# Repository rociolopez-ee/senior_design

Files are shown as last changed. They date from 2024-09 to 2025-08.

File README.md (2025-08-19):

# 🎧 MultiLink Portable Bluetooth Speaker - KiCad Design Files

This repository contains the full **KiCad project files** for the Multilink Portable Bluetooth Speaker designed by **Team 5 – Synergy Electronics** as part of the **Senior Design Capstone at San Diego State University (EE/COMPE 492)**.

## 📦 What’s Inside

This repository includes:
- **Schematic files** for the main and secondary speaker PCBs
- **PCB layout** for a custom 4-layer board
- **Bill of Materials (BOM)**
- **Gerber files** for fabrication
- **Custom footprints and symbols**

> 🎯 These designs were used to build and test a working multilink Bluetooth audio system using STM32/ATmega microcontrollers, BM83 Bluetooth modules, and a custom audio amplification chain.

---

## 🔧 Project Overview

The MultiLink Portable Bluetooth Speaker was designed to:
- Support **multi-speaker synchronized audio** via BM83 Bluetooth modules (host/embedded mode)
- Include **custom power amplifier** and **op-amp gain stages** (LF353 + discrete PA)
- Be powered by **20V DeWalt tool batteries**
- Use **custom enclosures** built from birch wood and plexiglass

🧠 PCB design and layout were done using KiCad 7 and included thermal planning, decoupling, and signal integrity improvements based on EMI/grounding test results.

---

## 🧪 PCB Design Highlights

- ✍️ **4-layer PCB**, designed for both signal integrity and ease of debugging
- 🔁 **Op-amp gain stage** (V=4.3) before power amplifier (V=2.2) for total gain ≈ 9.4 V/V
- 💡 **BM83 Bluetooth module** with UART interface to microcontroller
- 🔌 **Volume, pairing, and power buttons** routed via microcontroller
- 🌡️ **Thermal design** included heatsinks for voltage regulator and amplifier transistors
- 🛠️ Manual fixes applied to final board: jumper wires and capacitor routing corrections

---
🎥 Project Demo: [YouTube Video](https://youtube.com/shorts/QWg84WqX6ao?feature=share)
---

## 👥 Team Members

- **Rocio Lopez** – Project Manager, Lead PCB Designer  
- **Po-Jui Su** – Power Systems Engineer  
- **Ryan Minsky** – Firmware Engineer ([@rminsky42](https://github.com/rminsky42))
- **Giuseppe Aiello** – Enclosure Designer, Secondary PCB Assembler  
- **Jeffrey Chin** – Project Coordinator  

---

## ⚠️ Disclaimer

This repository contains files for educational and demonstration purposes. No commercial use is authorized.

---

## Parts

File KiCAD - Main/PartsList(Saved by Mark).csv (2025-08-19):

Reference | Value | Datasheet | Footprint | Qty | DNP
20v1,Analog1,Audio1,Audio2,PAOut1,RX1,TP1,TP2,TP3,TP4,TPQ1,TPQ2,TX1 | TestPoint | ~ | -- mixed values -- | 13
C1 | 0.33uF | ~ | Capacitor_THT:C_Disc_D4.7mm_W2.5mm_P5.00mm | 1
C2 | 0.1uF | ~ | Capacitor_THT:C_Disc_D4.7mm_W2.5mm_P5.00mm | 1
C3,C7,C8 | 1uF | ~ | Capacitor_THT:C_Disc_D4.7mm_W2.5mm_P5.00mm | 3
C4 | 1nF | ~ | Capacitor_THT:C_Disc_D4.7mm_W2.5mm_P5.00mm | 1
C5 | 0.22uF | ~ | Capacitor_THT:C_Disc_D4.7mm_W2.5mm_P5.00mm | 1
C6 | 1000uF | ~ | Capacitor_THT:C_Disc_D4.7mm_W2.5mm_P5.00mm | 1
C9 | .1uF | ~ | Capacitor_THT:C_Disc_D4.7mm_W2.5mm_P5.00mm | 1
D1,D2 | 1N4148 | https://assets.nexperia.com/documents/data-sheet/1N4148_1N4448.pdf | Diode_THT:D_DO-15_P12.70mm_Horizontal | 2
D3,D4 | LED | ~ | LED_THT:LED_D3.0mm | 2
J1,J2 | Conn_01x01 | ~ | TestPoint:TestPoint_Keystone_5010-5014_Multipurpose | 2
J3,J7 | Conn_01x02 | ~ | Connector_PinHeader_2.54mm:PinHeader_1x02_P2.54mm_Vertical | 2
J4 | 6120XX21621_61200621621 |  | 61200621621:61200621621 | 1
J5,J6 | Conn_01x04 | ~ | Connector_PinHeader_2.00mm:PinHeader_1x04_P2.00mm_Vertical | 2
J8,J9,J11,J12 | Conn_01x12 | ~ | Connector_PinHeader_2.54mm:PinHeader_1x12_P2.54mm_Vertical | 4
J10 | Screw_Terminal_01x02 | ~ | TerminalBlock_Phoenix:TerminalBlock_Phoenix_MKDS-1,5-2-5.08_1x02_P5.08mm_Horizontal | 1
Q1,Q2 | BSS138 | https://www.onsemi.com/pub/Collateral/BSS138-D.PDF | Package_TO_SOT_SMD:SOT-23-3 | 2
Q3,Q5 | 2N3904 | https://www.onsemi.com/pub/Collateral/2N3903-D.PDF | Package_TO_SOT_THT:TO-92_Wide | 2
Q4 | 2N3906 | https://www.onsemi.com/pub/Collateral/2N3906-D.PDF | Package_TO_SOT_THT:TO-92_Wide | 1
Q6 | 2SB817 | http://skory.gylcomp.hu/alkatresz/2SB817.pdf | Package_TO_SOT_THT:TO-220-3_Vertical | 1
Q7 | 2SD1047 | http://www.st.com/resource/en/datasheet/2sd1047.pdf | Package_TO_SOT_THT:TO-220-3_Vertical | 1
R1,R2,R4,R5,R6,R7,R8,R16,R17 | 10k | ~ | Resistor_THT:R_Axial_DIN0309_L9.0mm_D3.2mm_P12.70mm_Horizontal | 9
R3 | 5k | ~ | Resistor_THT:R_Axial_DIN0309_L9.0mm_D3.2mm_P12.70mm_Horizontal | 1
R9,R10 | 2k | ~ | Resistor_THT:R_Axial_DIN0309_L9.0mm_D3.2mm_P12.70mm_Horizontal | 2
R11 | 3.3k | ~ | Resistor_THT:R_Axial_DIN0309_L9.0mm_D3.2mm_P12.70mm_Horizontal | 1
R12,R14 | 4.7k | ~ | Resistor_THT:R_Axial_DIN0309_L9.0mm_D3.2mm_P12.70mm_Horizontal | 2
R13 | 1000 | ~ | Resistor_THT:R_Axial_DIN0309_L9.0mm_D3.2mm_P12.70mm_Horizontal | 1
R15 | 12k | ~ | Resistor_THT:R_Axial_DIN0309_L9.0mm_D3.2mm_P12.70mm_Horizontal | 1
R18,R19 | 0.22 | ~ | Resistor_THT:R_Axial_DIN0309_L9.0mm_D3.2mm_P12.70mm_Horizontal | 2
RV1 | R_Potentiometer_US | ~ | Potentiometer_THT:Potentiometer_Bourns_3386P_Vertical | 1
U1 | L78L05_TO220 | http://www.st.com/content/ccc/resource/technical/document/datasheet/15/55/e5/aa/23/5b/43/fd/CD00000446.pdf/files/CD00000446.pdf/jcr:content/translations/en.CD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 | Package_TO_SOT_THT:TO-220-3_Vertical | 1
U2 | ATmega328PB-A | http://ww1.microchip.com/downloads/en/DeviceDoc/40001906C.pdf | Package_QFP:TQFP-32_7x7mm_P0.8mm | 1
U3 | LF353N | https://www.ti.com/lit/ds/symlink/lf353-n.pdf | Package_DIP:DIP-8_W7.62mm_Socket | 1
U4 | Microchip_BM83 | https://ww1.microchip.com/downloads/aemDocuments/documents/WSG/ProductDocuments/DataSheets/70005402E.pdf | RF_Module:Microchip_BM83 | 1

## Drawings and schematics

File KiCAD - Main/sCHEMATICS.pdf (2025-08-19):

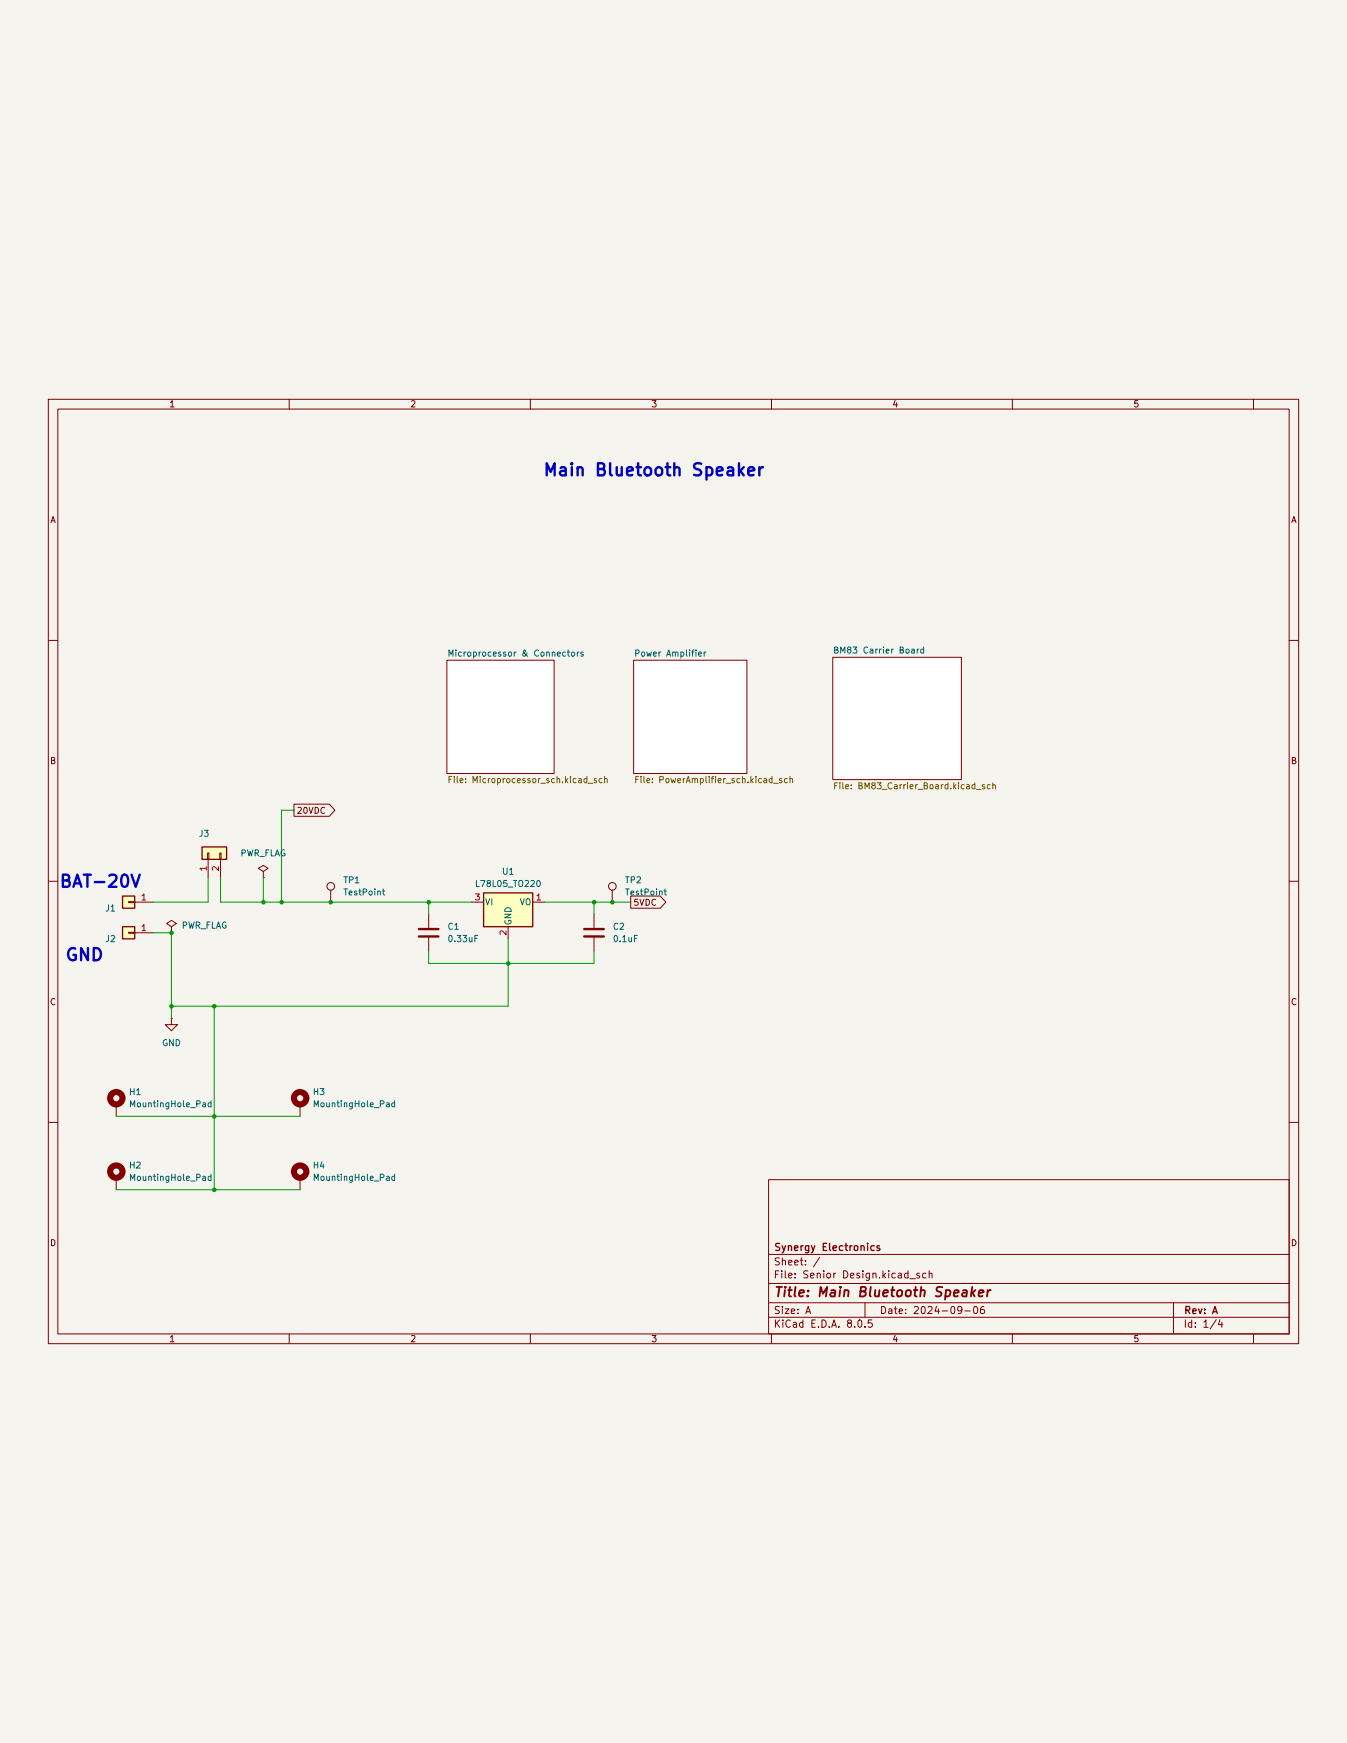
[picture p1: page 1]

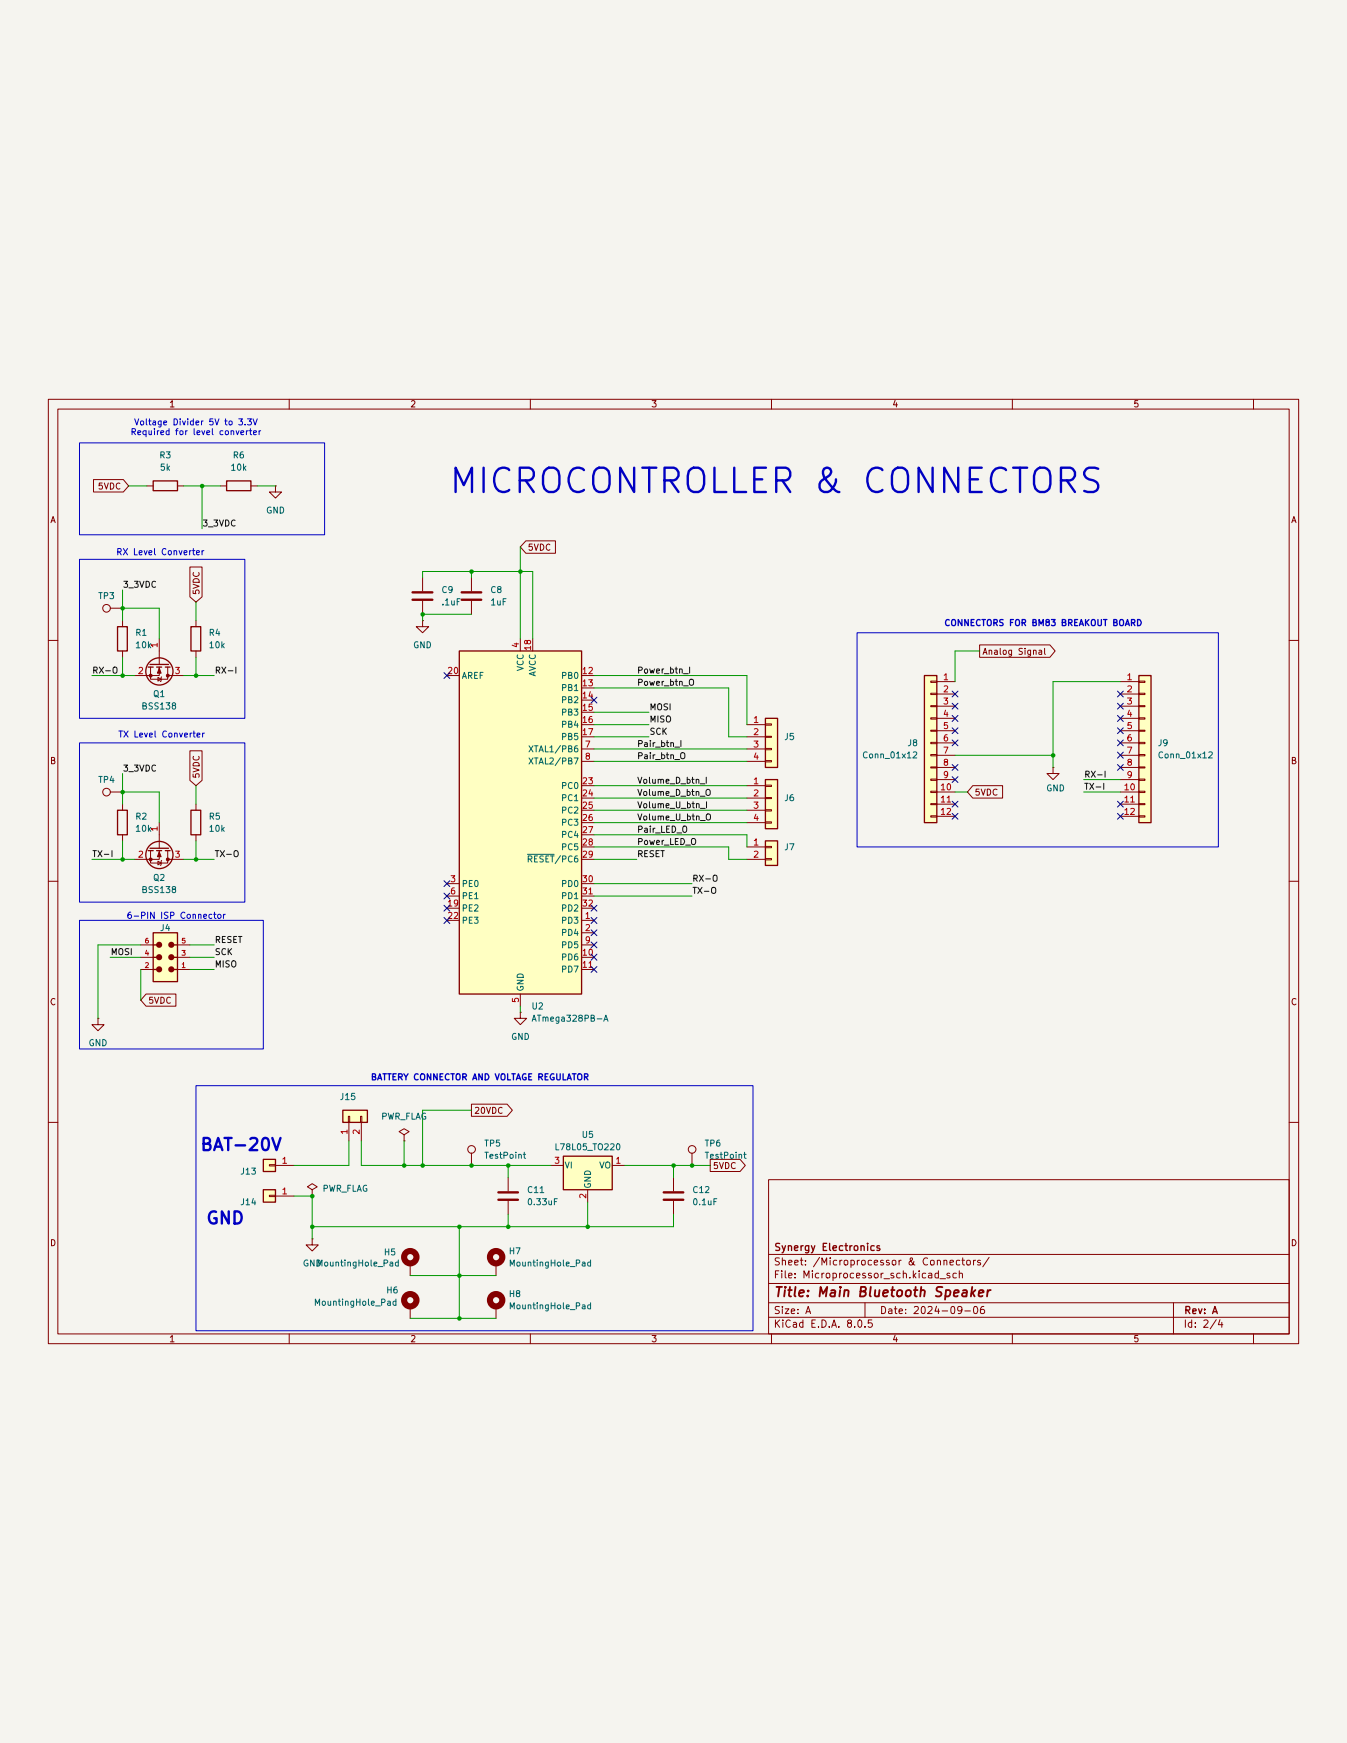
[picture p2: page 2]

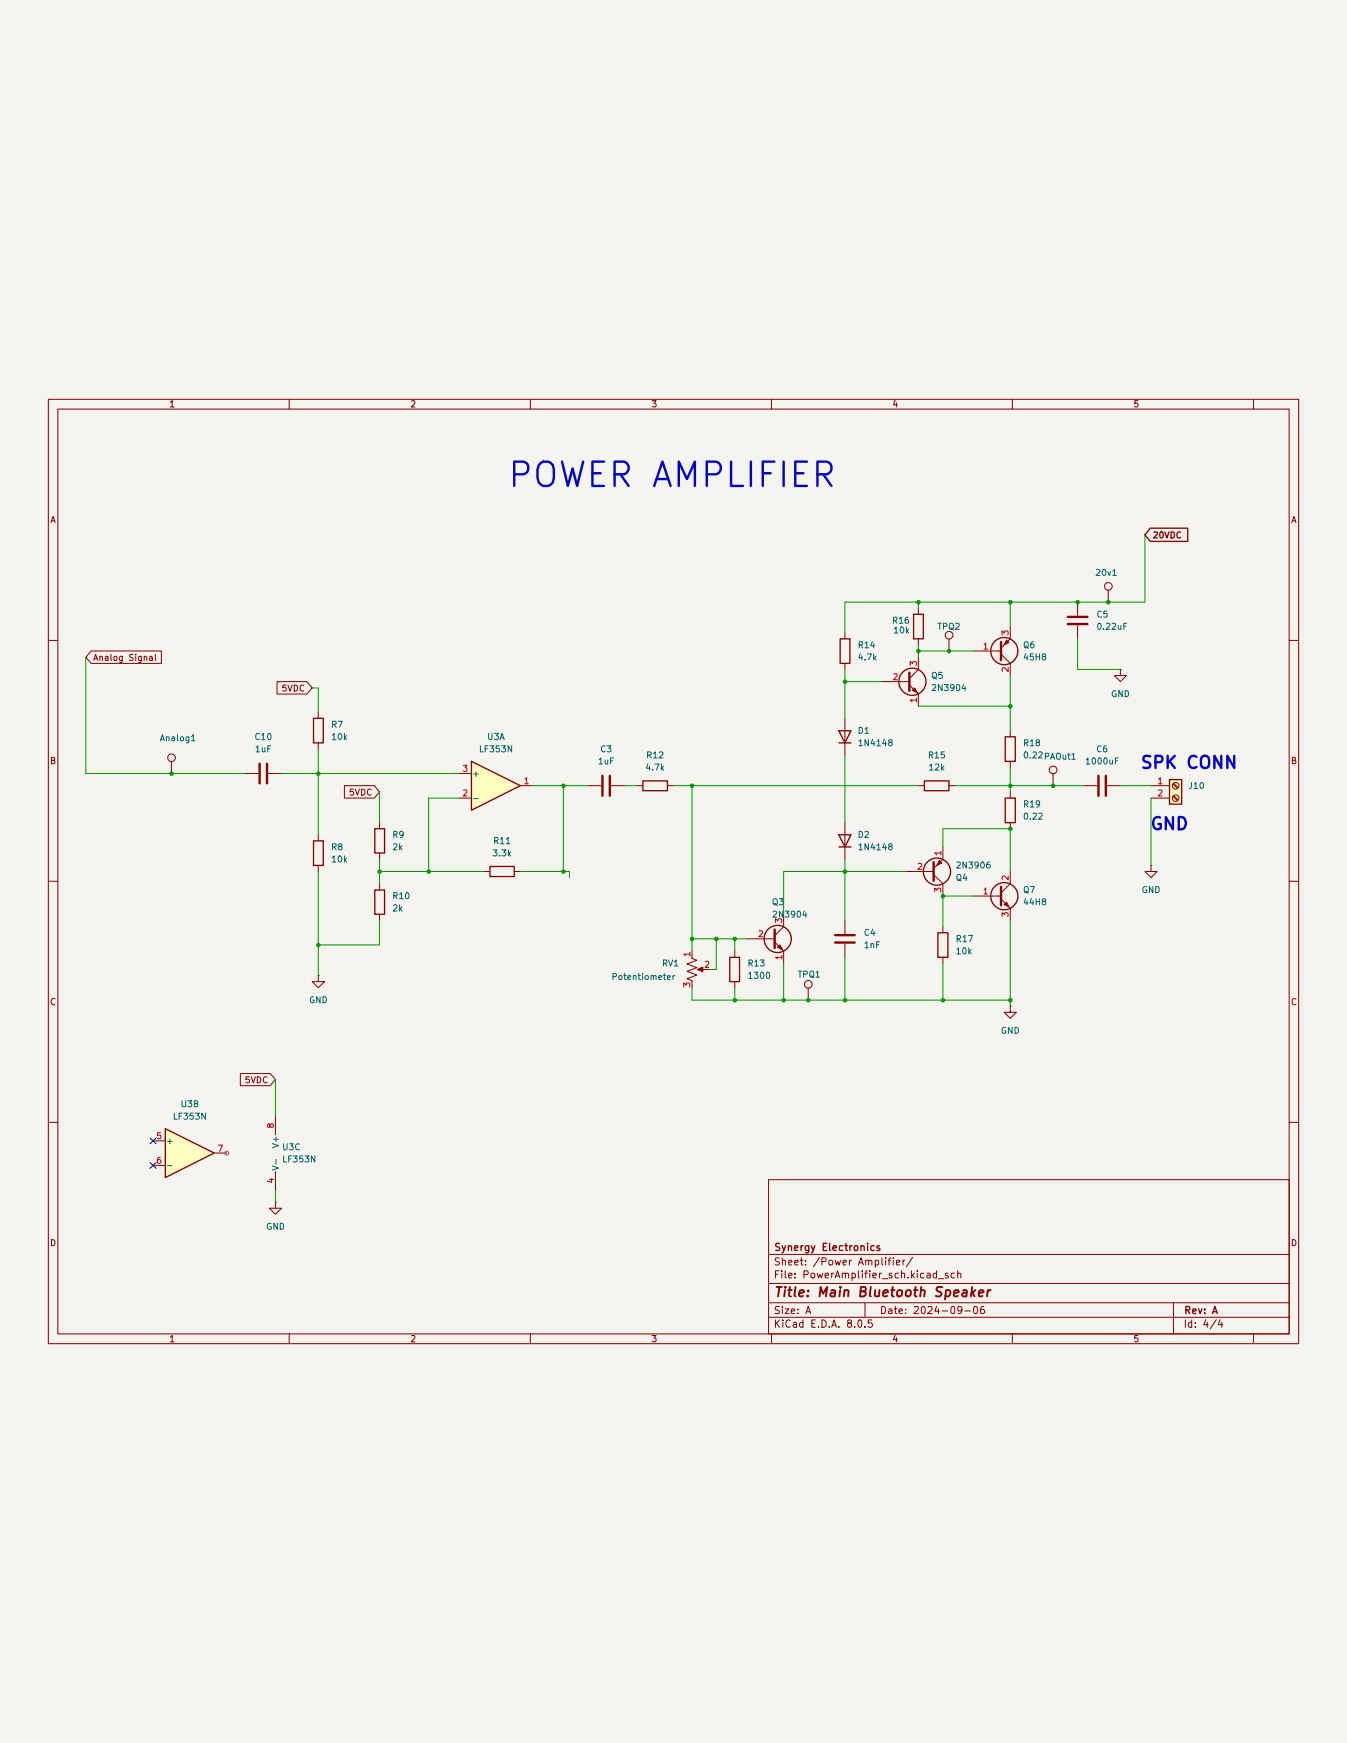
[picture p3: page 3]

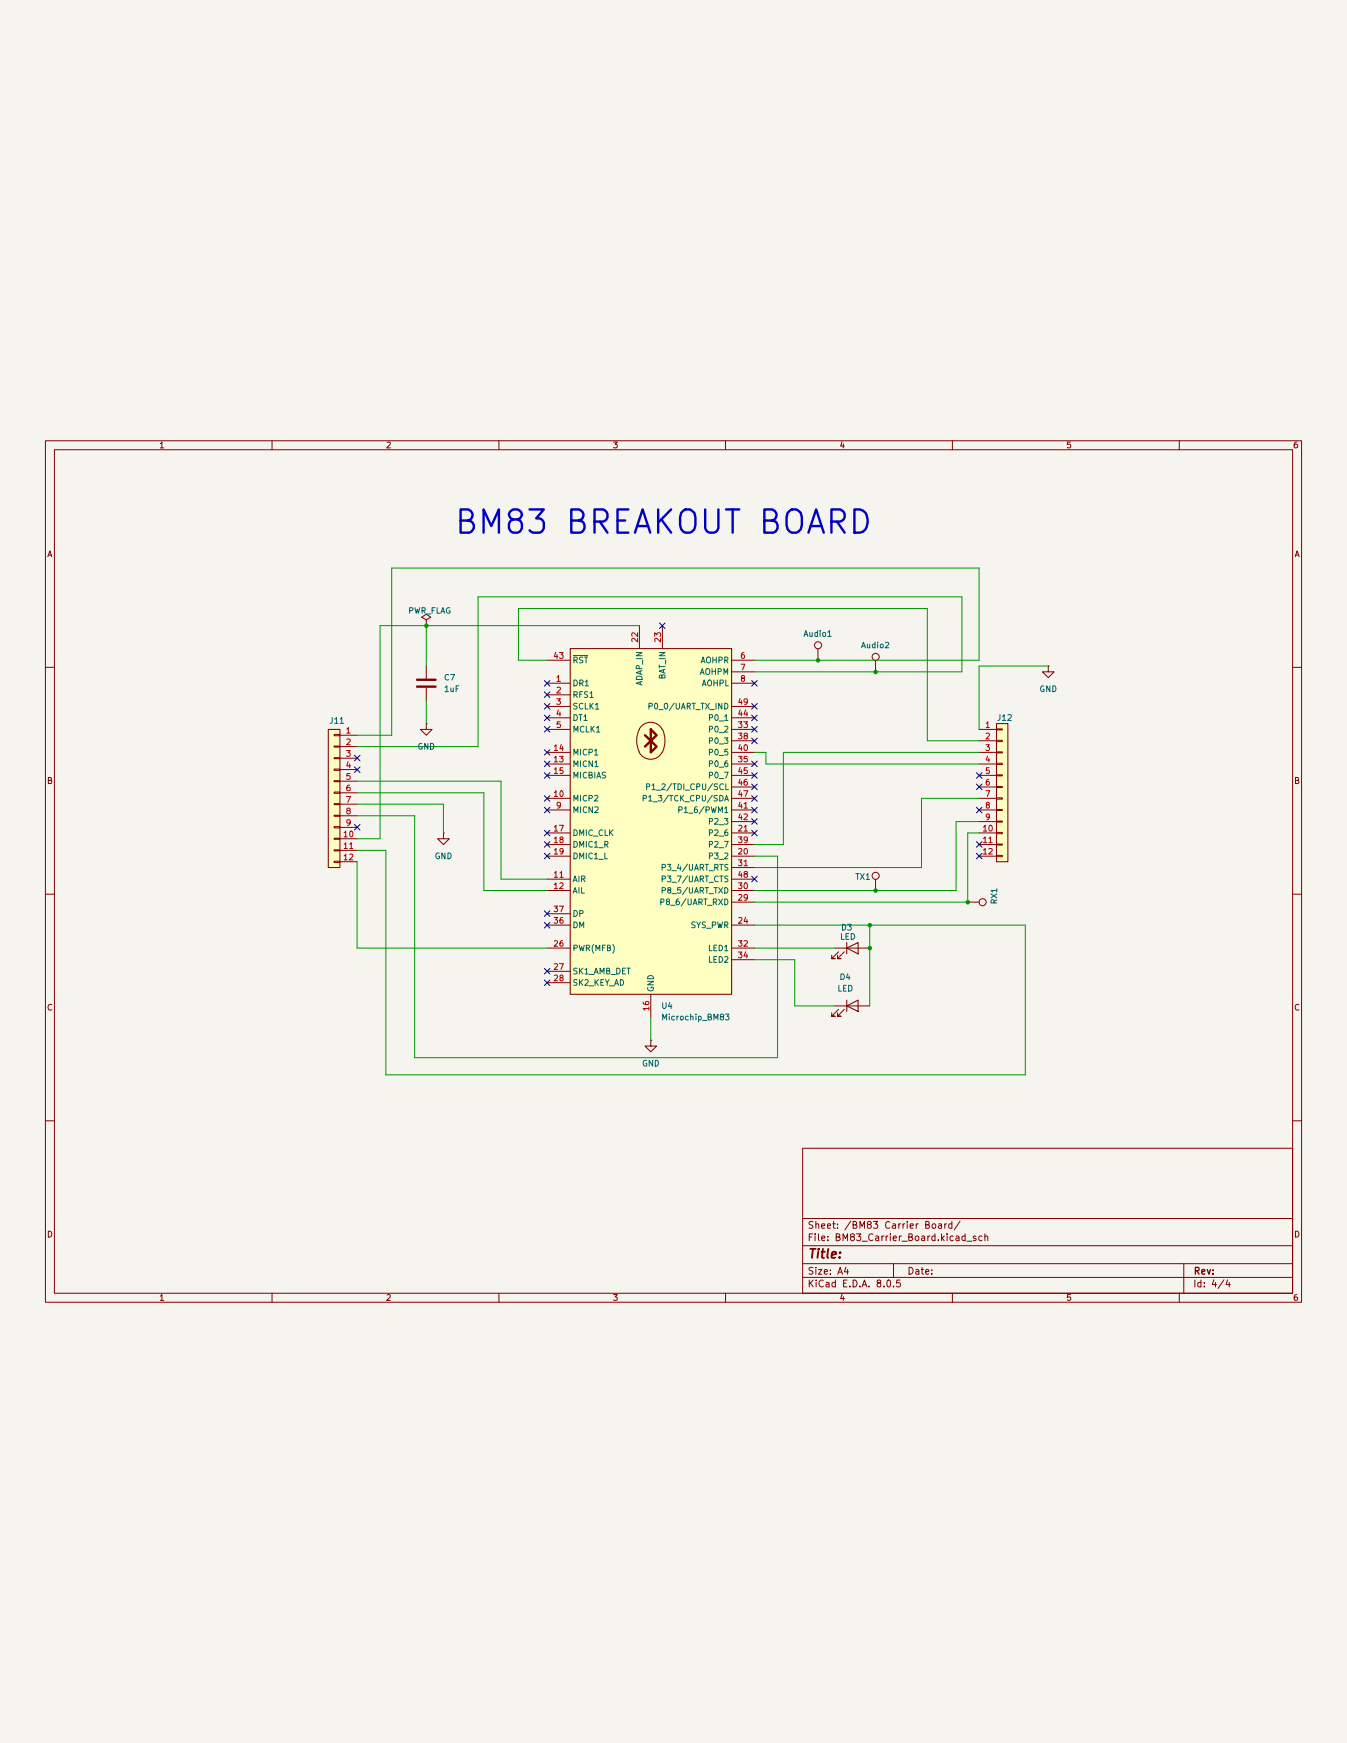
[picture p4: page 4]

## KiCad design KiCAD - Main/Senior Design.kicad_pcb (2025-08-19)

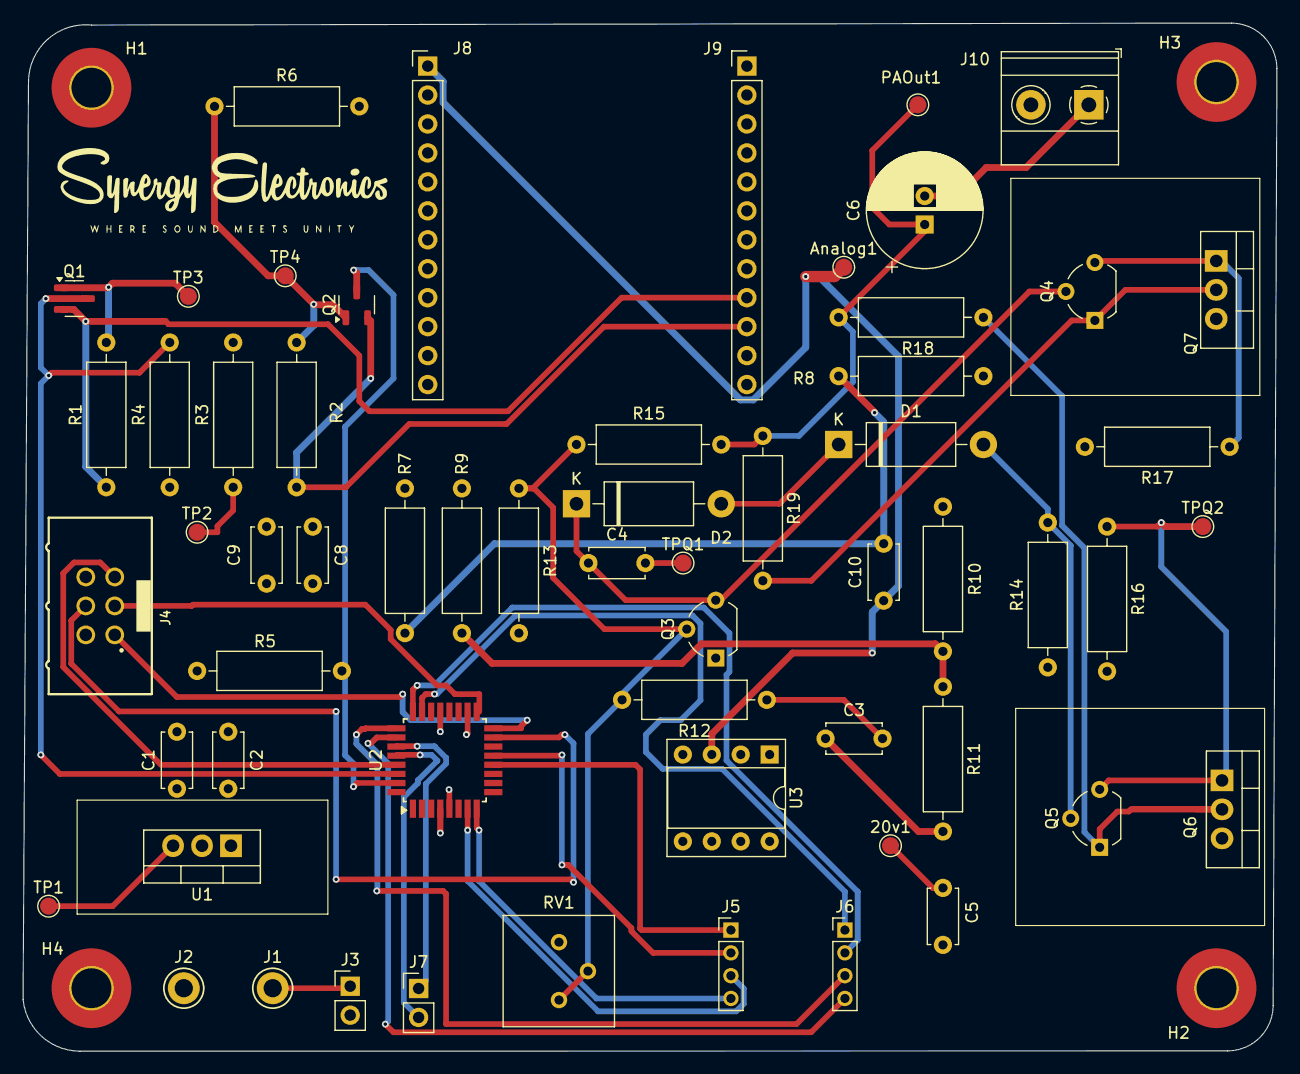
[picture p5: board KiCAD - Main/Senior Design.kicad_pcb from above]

Board: 4 copper layers, 110.0 x 90.2 mm, 64 parts (0 on the bottom side), 38 nets.

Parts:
20v1: TestPoint; TestPoint_Pad_D1.5mm
Analog1: TestPoint; TestPoint_Pad_D1.5mm
C1: 0.33uF; C_Disc_D4.7mm_W2.5mm_P5.00mm
C2: 0.1uF; C_Disc_D4.7mm_W2.5mm_P5.00mm
C3, C8, C10: 1uF; C_Disc_D4.7mm_W2.5mm_P5.00mm
C4: 1nF; C_Disc_D4.7mm_W2.5mm_P5.00mm
C5: 0.22uF; C_Disc_D4.7mm_W2.5mm_P5.00mm
C6: 1000uF; CP_Radial_D10.0mm_P2.50mm
C9: .1uF; C_Disc_D4.7mm_W2.5mm_P5.00mm
D1, D2: 1N4148; D_DO-15_P12.70mm_Horizontal
H1, H2, H3, H4: MountingHole_Pad; MountingHole_3.5mm_Pad_TopBottom
J1, J2: Conn_01x01; TestPoint_Keystone_5010-5014_Multipurpose
J3, J7: Conn_01x02; PinHeader_1x02_P2.54mm_Vertical
J4: 6120XX21621_61200621621; 61200621621
J5, J6: Conn_01x04; PinHeader_1x04_P2.00mm_Vertical
J8, J9: Conn_01x12; PinHeader_1x12_P2.54mm_Vertical
J10: Screw_Terminal_01x02; TerminalBlock_Phoenix_MKDS-1,5-2-5.08_1x02_P5.08mm_Horizont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
PAOut1: TestPoint; TestPoint_Pad_D1.5mm
Q1, Q2: BSS138; SOT-23-3
Q3, Q5: 2N3904; TO-92_Wide
Q4: 2N3906; TO-92_Wide
Q6: D45H8; TO-220-3_Vertical
Q7: D44H8; TO-220-3_Vertical
R1, R2, R4, R5, R6, R7, R8, R16, R17: 10k; R_Axial_DIN0309_L9.0mm_D3.2mm_P12.70mm_Horizontal
R3: 5k; R_Axial_DIN0309_L9.0mm_D3.2mm_P12.70mm_Horizontal
R9, R10: 2k; R_Axial_DIN0309_L9.0mm_D3.2mm_P12.70mm_Horizontal
R11: 3.3k; R_Axial_DIN0309_L9.0mm_D3.2mm_P12.70mm_Horizontal
R12, R14: 4.7k; R_Axial_DIN0309_L9.0mm_D3.2mm_P12.70mm_Horizontal
R13: 1000; R_Axial_DIN0309_L9.0mm_D3.2mm_P12.70mm_Horizontal
R15: 12k; R_Axial_DIN0309_L9.0mm_D3.2mm_P12.70mm_Horizontal
R18, R19: 0.22; R_Axial_DIN0309_L9.0mm_D3.2mm_P12.70mm_Horizontal
RV1: R_Potentiometer_US; Potentiometer_Bourns_3386P_Vertical
TP1, TP2, TP3, TP4: TestPoint; TestPoint_Pad_D1.5mm
TPQ1, TPQ2: TestPoint; TestPoint_Pad_D1.5mm
U1: L78L05_TO220; TO-220-3_Vertical
U2: ATmega328PB-A; TQFP-32_7x7mm_P0.8mm
U3: LF353N; DIP-8_W7.62mm_Socket

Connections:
5VDC: C2.1, C8.1, C9.1, J4.2, J8.10, R3.1, R4.1, R5.1, R7.1, R9.1, TP2.1, U1.1 (VO), U2.4 (VCC), U2.18 (AVCC), U3.8 (V+)
20VDC: 20v1.1, C1.1, C5.1, J3.2, Q6.3 (E), R14.1, R16.2, TP1.1, U1.3 (VI)
/Microprocessor & Connectors/3_3VDC: Q1.1 (G), Q2.1 (G), R1.1, R2.1, R3.2, R6.1, TP3.1, TP4.1
/Microprocessor & Connectors/MISO: J4.1, U2.16 (PB4)
/Microprocessor & Connectors/MOSI: J4.4, U2.15 (PB3)
/Microprocessor & Connectors/Pair_LED_O: J7.1, U2.27 (PC4)
/Microprocessor & Connectors/Pair_btn_I: J5.3, U2.7 (XTAL1/PB6)
/Microprocessor & Connectors/Pair_btn_O: J5.4, U2.8 (XTAL2/PB7)
/Microprocessor & Connectors/Power_LED_O: J7.2, U2.28 (PC5)
/Microprocessor & Connectors/Power_btn_I: J5.1, U2.12 (PB0)
/Microprocessor & Connectors/Power_btn_O: J5.2, U2.13 (PB1)
/Microprocessor & Connectors/RESET: J4.5, U2.29 (~RESET/PC6)
/Microprocessor & Connectors/RX-I: J9.9, Q1.2 (S), R1.2
/Microprocessor & Connectors/RX-O: Q1.3 (D), R4.2, U2.30 (PD0)
/Microprocessor & Connectors/SCK: J4.3, U2.17 (PB5)
/Microprocessor & Connectors/TX-I: J9.10, Q2.2 (S), R2.2
/Microprocessor & Connectors/TX-O: Q2.3 (D), R5.2, U2.31 (PD1)
/Microprocessor & Connectors/Volume_D_btn_I: J6.1, U2.23 (PC0)
/Microprocessor & Connectors/Volume_D_btn_O: J6.2, U2.24 (PC1)
/Microprocessor & Connectors/Volume_U_btn_I: J6.3, U2.25 (PC2)
/Microprocessor & Connectors/Volume_U_btn_O: J6.4, U2.26 (PC3)
Analog Signal: Analog1.1, C10.1, J8.1, U3.3 (POSA)
GND: C1.2, C2.2, C4.2, C5.2, C8.2, C9.2, H1.1, H2.1, H3.1, H4.1, J2.1, J4.6, J8.7, J9.1, J10.2, Q3.1 (E), Q7.3 (E), R6.2, R8.2, R10.2, R13.2, R17.2, RV1.3, TPQ1.1, U1.2 (GND), U2.5 (GND), U2.21 (GND), U3.4 (V-)
unnamed: C3.1, R11.2
unnamed: C3.2, R12.1
unnamed: C6.1, PAOut1.1, R15.2, R18.2, R19.1
unnamed: D1.2 (A), Q5.2 (B), R14.2
unnamed: D1.1 (K), D2.2 (A)
unnamed: C4.1, D2.1 (K), Q3.3 (C), Q4.2 (B)
unnamed: J1.1, J3.1
unnamed: C6.2, J10.1
unnamed: Q3.2 (B), R12.2, R13.1, R15.1, RV1.1, RV1.2
unnamed: Q4.3 (C), Q7.1 (B), R17.1
unnamed: Q4.1 (E), Q7.2 (C), R19.2
unnamed: Q5.3 (C), Q6.1 (B), R16.1, TPQ2.1
unnamed: Q5.1 (E), Q6.2 (C), R18.1
unnamed: C10.2, R7.2, R8.1
unnamed: R9.2, R10.1, R11.1

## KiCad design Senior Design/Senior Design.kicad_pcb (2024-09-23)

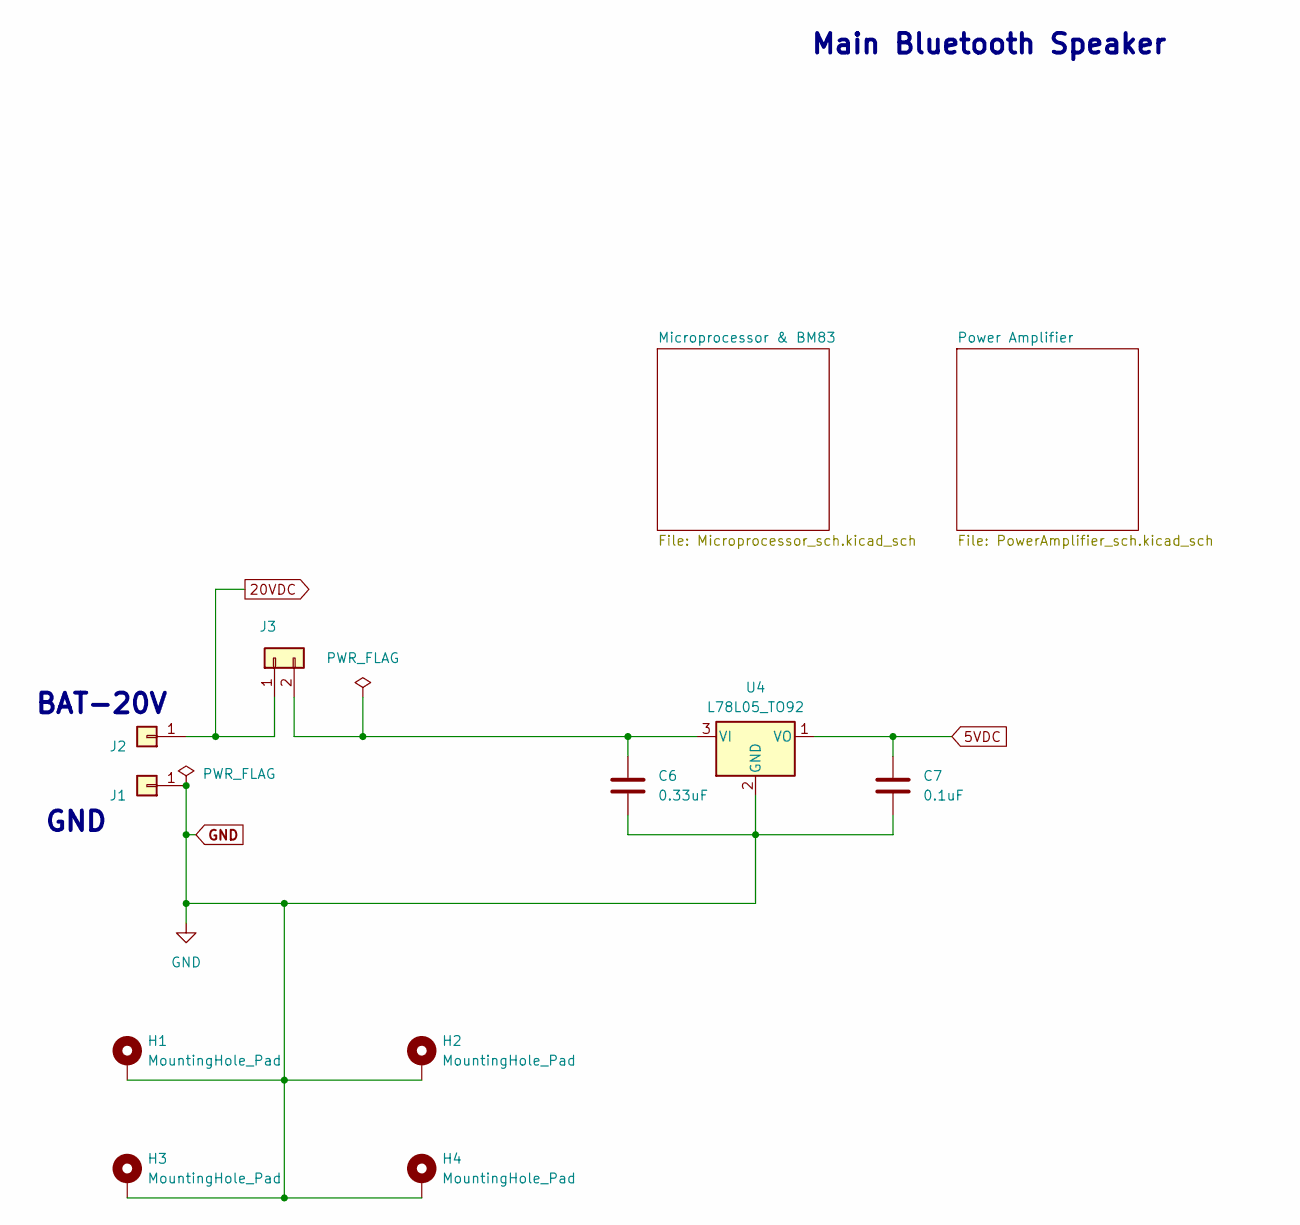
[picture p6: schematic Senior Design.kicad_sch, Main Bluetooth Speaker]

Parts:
C6: 0.33uF; C_Disc_D4.7mm_W2.5mm_P5.00mm
C7: 0.1uF; C_Disc_D4.7mm_W2.5mm_P5.00mm
H1, H2, H3, H4: MountingHole_Pad; MountingHole_3.5mm_Pad_TopBottom
J1, J2: Conn_01x01; TestPoint_Keystone_5010-5014_Multipurpose
J3: Conn_01x02; PinHeader_1x02_P2.54mm_Vertical
U4: L78L05_TO92; TO-92_Wide

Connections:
5VDC: C7.1, U4.1 (VO); also elsewhere on the board
20VDC: J2.1, J3.1; also elsewhere on the board
GND: C6.2, C7.2, H1.1, H2.1, H3.1, H4.1, J1.1, U4.2 (GND); also elsewhere on the board
unnamed: C6.1, J3.2, U4.3 (VI)

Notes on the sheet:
BAT-20V
GND
Main Bluetooth Speaker

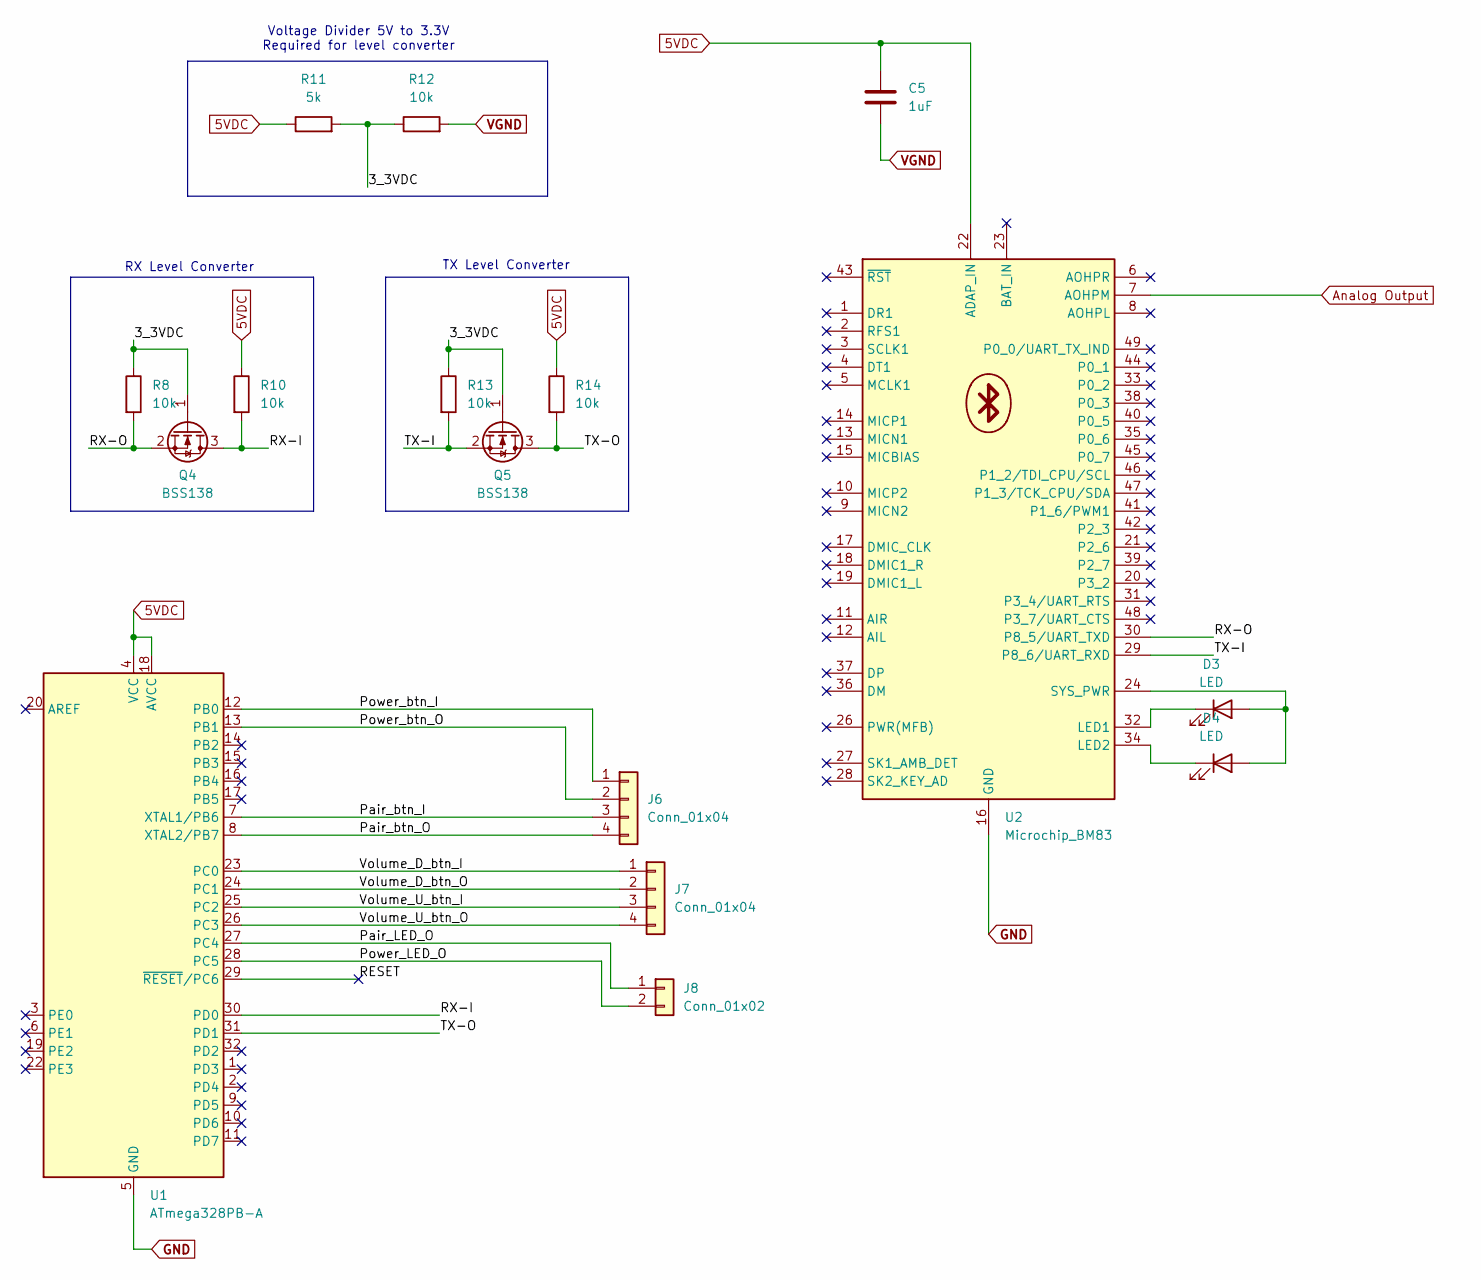
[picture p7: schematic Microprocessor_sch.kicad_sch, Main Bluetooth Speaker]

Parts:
C5: 1uF; C_Disc_D4.7mm_W2.5mm_P5.00mm
D3, D4: LED; LED_D5.0mm
J6, J7: Conn_01x04; PinHeader_1x04_P2.54mm_Vertical
J8: Conn_01x02; PinHeader_1x02_P2.54mm_Vertical
Q4, Q5: BSS138; SOT-23-3
R8, R10, R12, R13, R14: 10k; R_Axial_DIN0309_L9.0mm_D3.2mm_P12.70mm_Horizontal
R11: 5k; R_Axial_DIN0309_L9.0mm_D3.2mm_P12.70mm_Horizontal
U1: ATmega328PB-A; TQFP-32_7x7mm_P0.8mm
U2: Microchip_BM83

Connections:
5VDC: C5.1, R10.1, R11.1, R14.1, U1.4 (VCC), U1.18 (AVCC), U2.22 (ADAP_IN); also elsewhere on the board
/Microprocessor & BM83/3_3VDC: Q4.1 (G), Q5.1 (G), R8.1, R11.2, R12.1, R13.1
/Microprocessor & BM83/Pair_LED_O: J8.1, U1.27 (PC4)
/Microprocessor & BM83/Pair_btn_I: J6.3, U1.7 (XTAL1/PB6)
/Microprocessor & BM83/Pair_btn_O: J6.4, U1.8 (XTAL2/PB7)
/Microprocessor & BM83/Power_LED_O: J8.2, U1.28 (PC5)
/Microprocessor & BM83/Power_btn_I: J6.1, U1.12 (PB0)
/Microprocessor & BM83/Power_btn_O: J6.2, U1.13 (PB1)
/Microprocessor & BM83/RESET: U1.29 (~RESET/PC6)
/Microprocessor & BM83/RX-I: Q4.3 (D), R10.2, U1.30 (PD0)
/Microprocessor & BM83/RX-O: Q4.2 (S), R8.2, U2.30 (P8_5/UART_TXD)
/Microprocessor & BM83/TX-I: Q5.2 (S), R13.2, U2.29 (P8_6/UART_RXD)
/Microprocessor & BM83/TX-O: Q5.3 (D), R14.2, U1.31 (PD1)
/Microprocessor & BM83/Volume_D_btn_I: J7.1, U1.23 (PC0)
/Microprocessor & BM83/Volume_D_btn_O: J7.2, U1.24 (PC1)
/Microprocessor & BM83/Volume_U_btn_I: J7.3, U1.25 (PC2)
/Microprocessor & BM83/Volume_U_btn_O: J7.4, U1.26 (PC3)
Analog Output: U2.7 (AOHPM); also elsewhere on the board
GND: U1.5 (GND), U1.21 (GND), U2.16 (GND), U2.50 (GND), U2.56 (GND), U2.57 (GND); also elsewhere on the board
unnamed: D3.2 (A), D4.2 (A), U2.24 (SYS_PWR)
unnamed: D3.1 (K), U2.32 (LED1)
unnamed: D4.1 (K), U2.34 (LED2)
VGND: C5.2, R12.2

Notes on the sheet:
RX Level Converter
TX Level Converter
Voltage Divider 5V to 3.3V Required for level converter

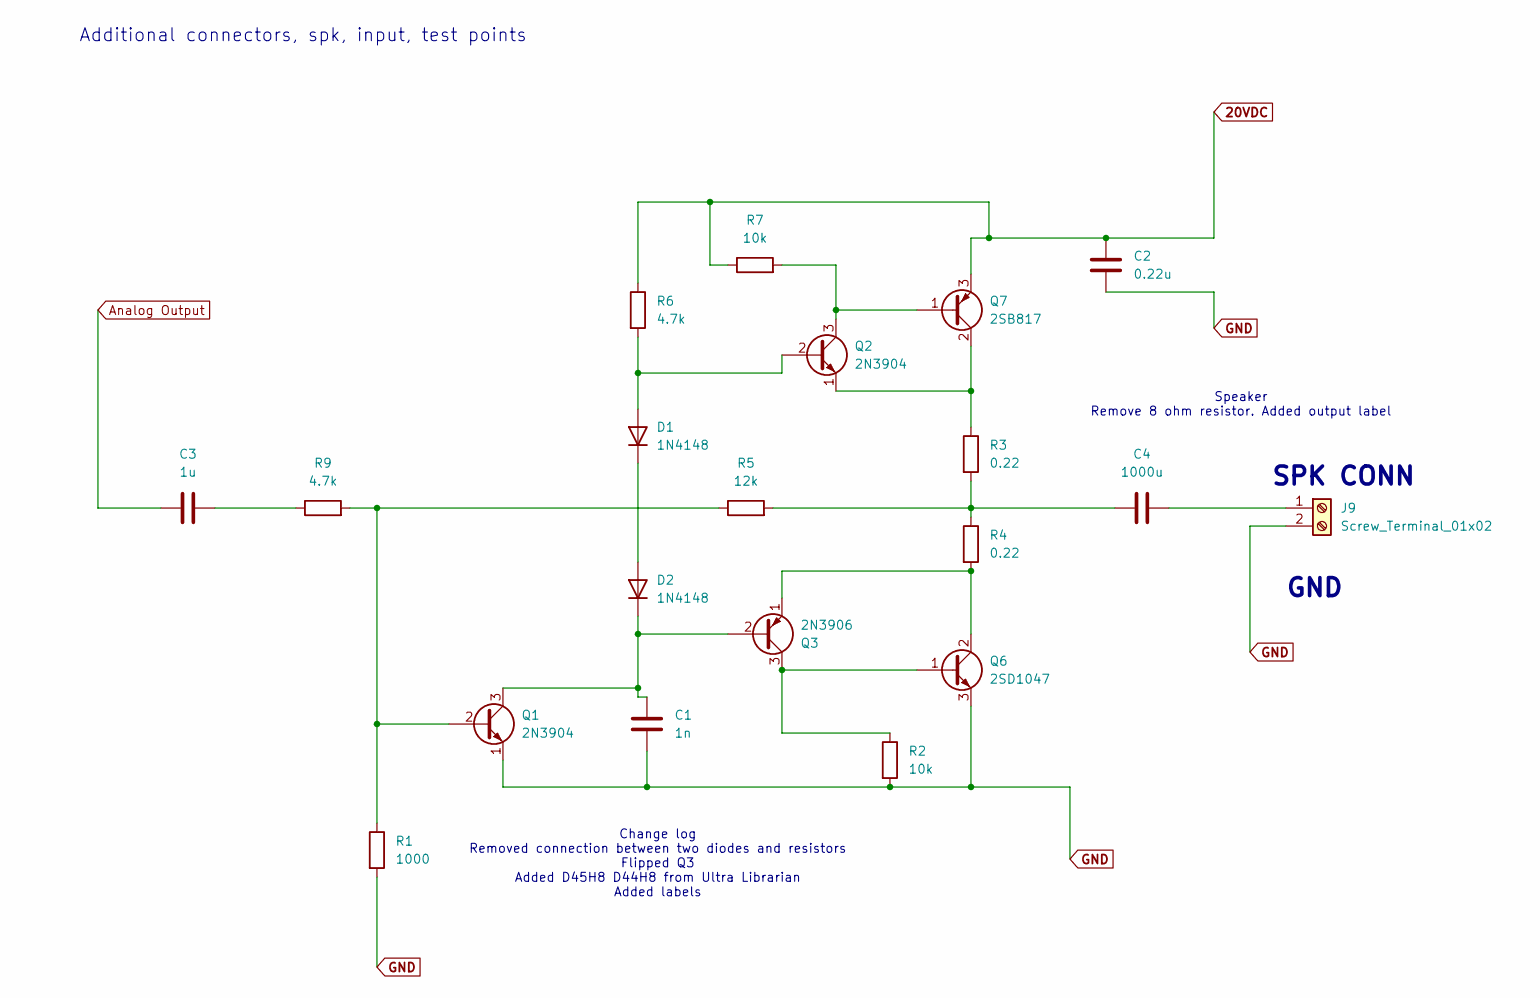
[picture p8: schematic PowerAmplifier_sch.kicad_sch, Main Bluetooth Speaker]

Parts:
C1: 1n; C_Disc_D4.7mm_W2.5mm_P5.00mm
C2: 0.22u; C_Disc_D4.7mm_W2.5mm_P5.00mm
C3: 1u; C_Disc_D4.7mm_W2.5mm_P5.00mm
C4: 1000u; C_Disc_D4.7mm_W2.5mm_P5.00mm
D1, D2: 1N4148; R_Axial_DIN0309_L9.0mm_D3.2mm_P12.70mm_Horizontal
J9: Screw_Terminal_01x02; TerminalBlock_Phoenix_MKDS-1,5-2-5.08_1x02_P5.08mm_Horizont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
Q1, Q2: 2N3904; TO-92_Wide
Q3: 2N3906; TO-92_Wide
Q6: 2SD1047; TO-220-3_Vertical
Q7: 2SB817; TO-220-3_Vertical
R1: 1000; R_Axial_DIN0309_L9.0mm_D3.2mm_P12.70mm_Horizontal
R2, R7: 10k; R_Axial_DIN0309_L9.0mm_D3.2mm_P12.70mm_Horizontal
R3, R4: 0.22; R_Axial_DIN0309_L9.0mm_D3.2mm_P12.70mm_Horizontal
R5: 12k; R_Axial_DIN0309_L9.0mm_D3.2mm_P12.70mm_Horizontal
R6, R9: 4.7k; R_Axial_DIN0309_L9.0mm_D3.2mm_P12.70mm_Horizontal

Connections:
20VDC: C2.1, Q7.3 (E), R6.1, R7.1; also elsewhere on the board
Analog Output: C3.1; also elsewhere on the board
GND: C1.2, C2.2, J9.2, Q1.1 (E), Q6.3 (E), R1.2, R2.2; also elsewhere on the board
unnamed: C3.2, R9.1
unnamed: C4.1, R3.2, R4.1, R5.2
unnamed: D1.2 (A), Q2.2 (B), R6.2
unnamed: D1.1 (K), D2.2 (A)
unnamed: C1.1, D2.1 (K), Q1.3 (C), Q3.2 (B)
unnamed: C4.2, J9.1
unnamed: Q1.2 (B), R1.1, R5.1, R9.2
unnamed: Q2.3 (C), Q7.1 (B), R7.2
unnamed: Q2.1 (E), Q7.2 (C), R3.1
unnamed: Q3.3 (C), Q6.1 (B), R2.1
unnamed: Q3.1 (E), Q6.2 (C), R4.2

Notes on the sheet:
Speaker Remove 8 ohm resistor. Added output label
Change log Removed connection between two diodes and resistors Flipped Q3 Added D45H8 D44H8 from Ultra Librarian Added labels
GND
SPK CONN
Additional connectors, spk, input, test points

Board: 2 copper layers, 47 parts (0 on the bottom side), 35 nets, no tracks yet.

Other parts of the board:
U3: L78L05_SO8; TO-92_Wide

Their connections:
5VDC: U3.1 (OUT); also elsewhere on the board
GND: U3.2 (GND), U3.3 (GND); also elsewhere on the board

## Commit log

2024-09-23 KiCAD files
    Files with changes up to 9/23/24, I showed Professor Dorr the schematic and he mentioned L78L05 might need to be updated to support higher current for both BM83 and Atmega, non of the Atmel Ice schem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
    [BluetoothModule_sch.kicad_sch, LEDsPorwerSource_sch.kicad_sch, Microprocessor_sch.kicad_sch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]
2025-08-19 Add files via upload
    Final Rev of PCB
    [Microprocessor_sch.kicad_sch, PartsList(Saved by Mark).csv, PartsList.csv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]
